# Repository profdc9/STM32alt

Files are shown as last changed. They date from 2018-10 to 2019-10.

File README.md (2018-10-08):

This is a Bluepill-compatible devboard for the STM32F103C8T6 microcontroller.
It uses all through-hole parts except for the STM32F103C8T6/STM32F103CBT6 microcontroller
and is intended to be an alternative to the Bluepill that is easier to assemble
should the Bluepill not be available or suitable.  It is somewhat optimized to be
RFI resistant given it is a two-layer board
This material is copyrighted by Daniel Marks (KW4TI) and licensed under
the Creative Commons License CC-BY-SA 4.0.  Software is copyrighted using the zlib
open-source license.

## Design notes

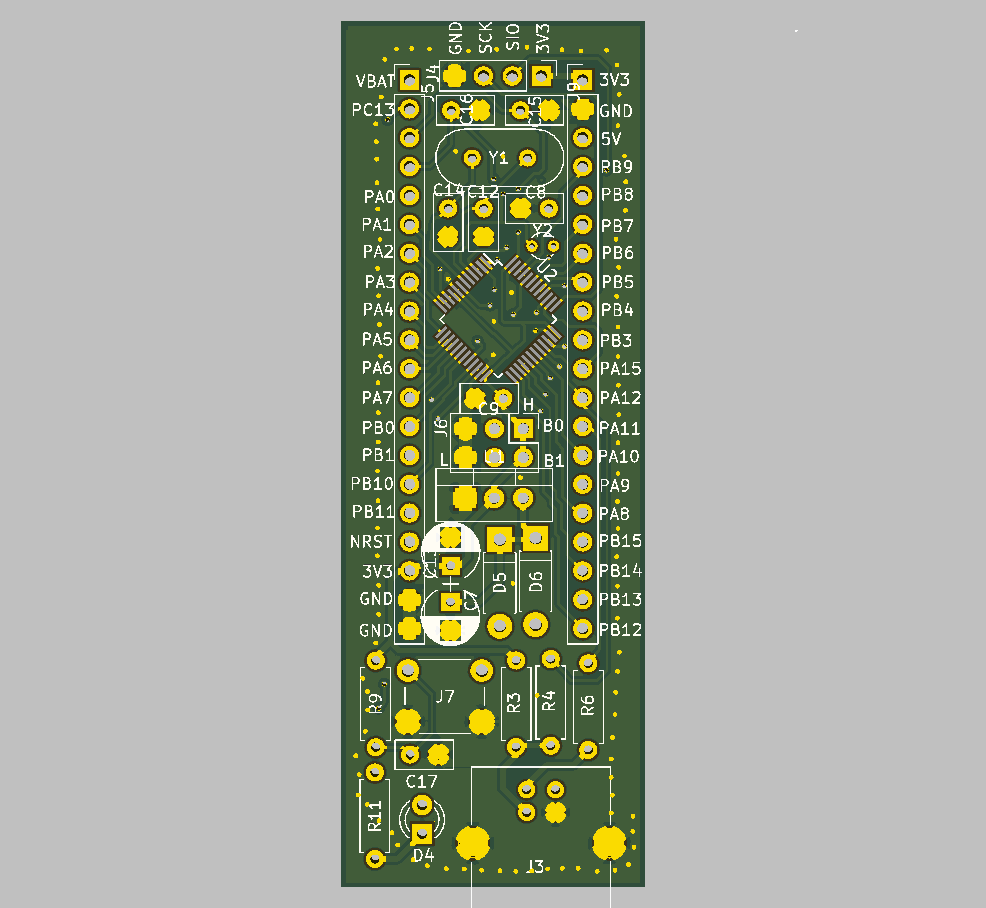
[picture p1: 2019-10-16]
STM32alt-bare.png

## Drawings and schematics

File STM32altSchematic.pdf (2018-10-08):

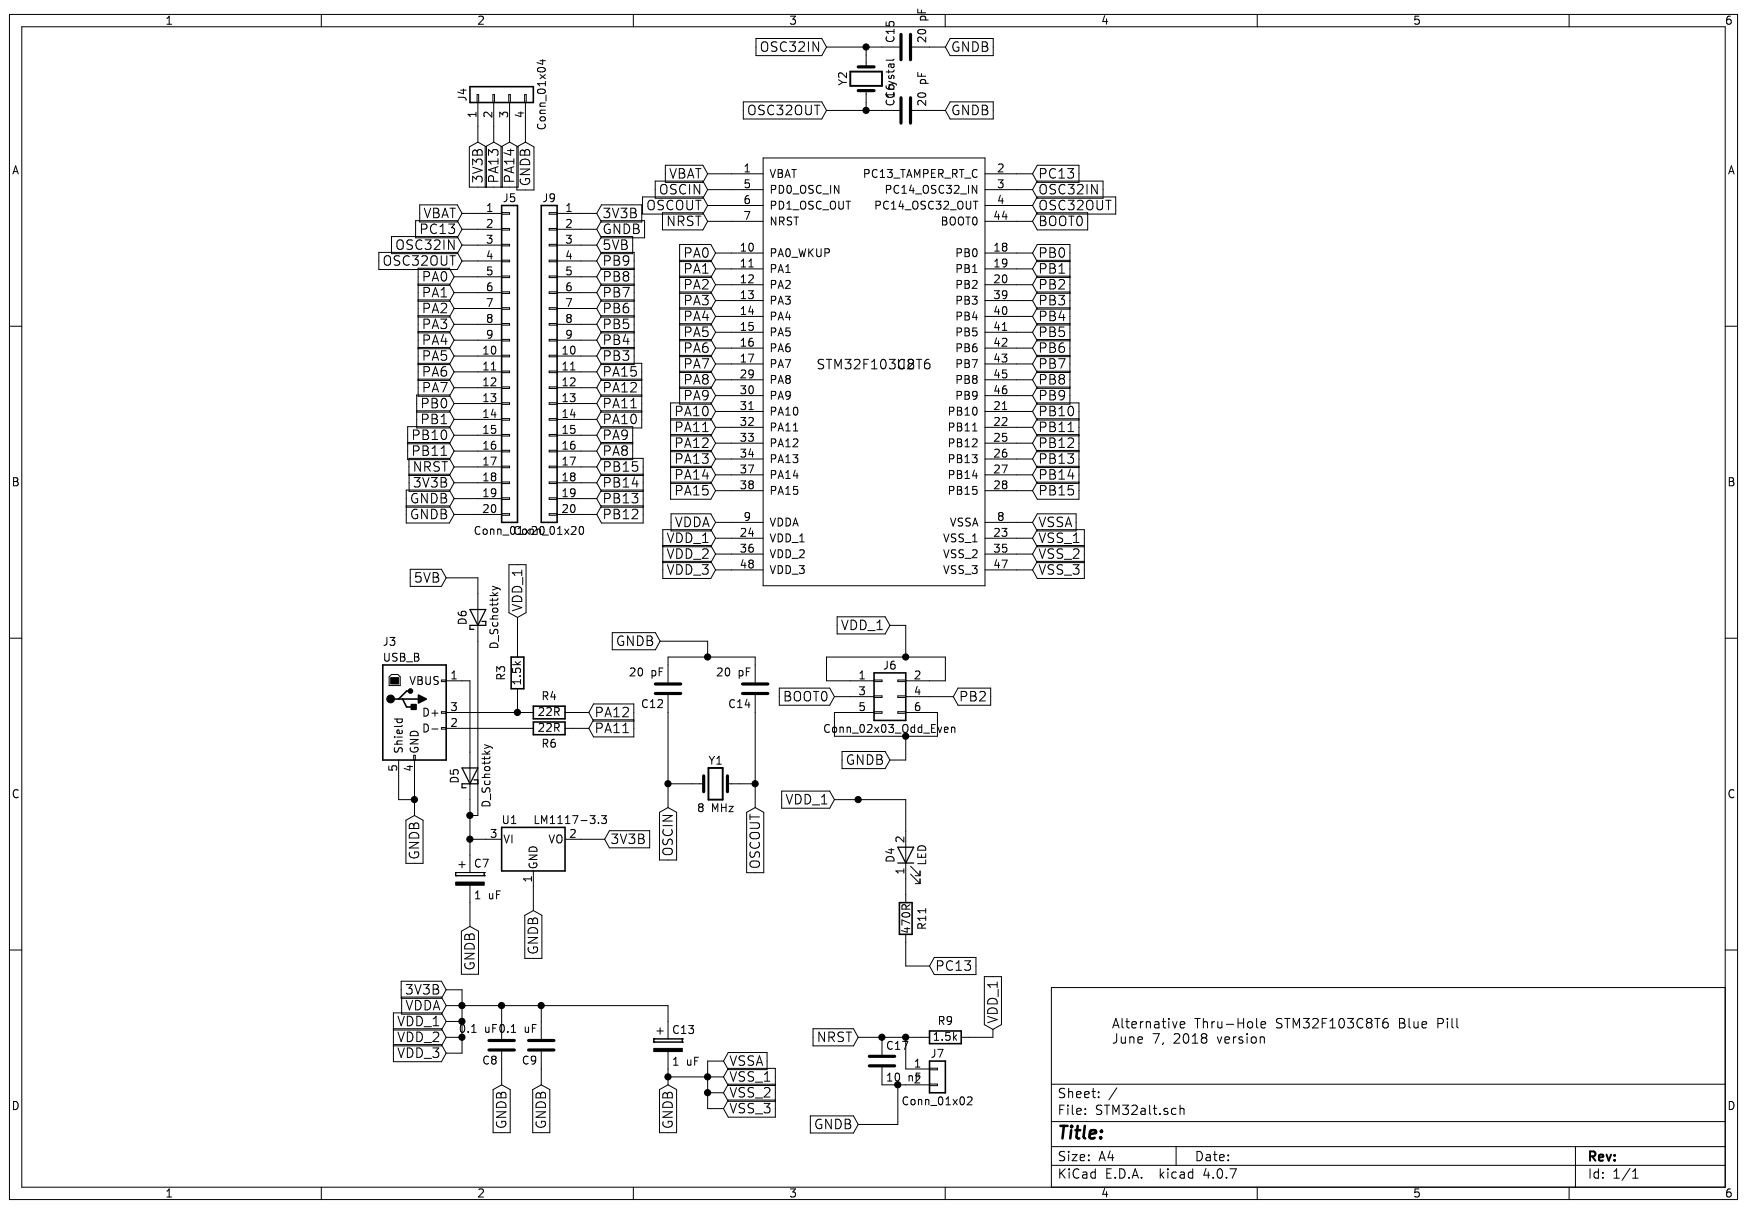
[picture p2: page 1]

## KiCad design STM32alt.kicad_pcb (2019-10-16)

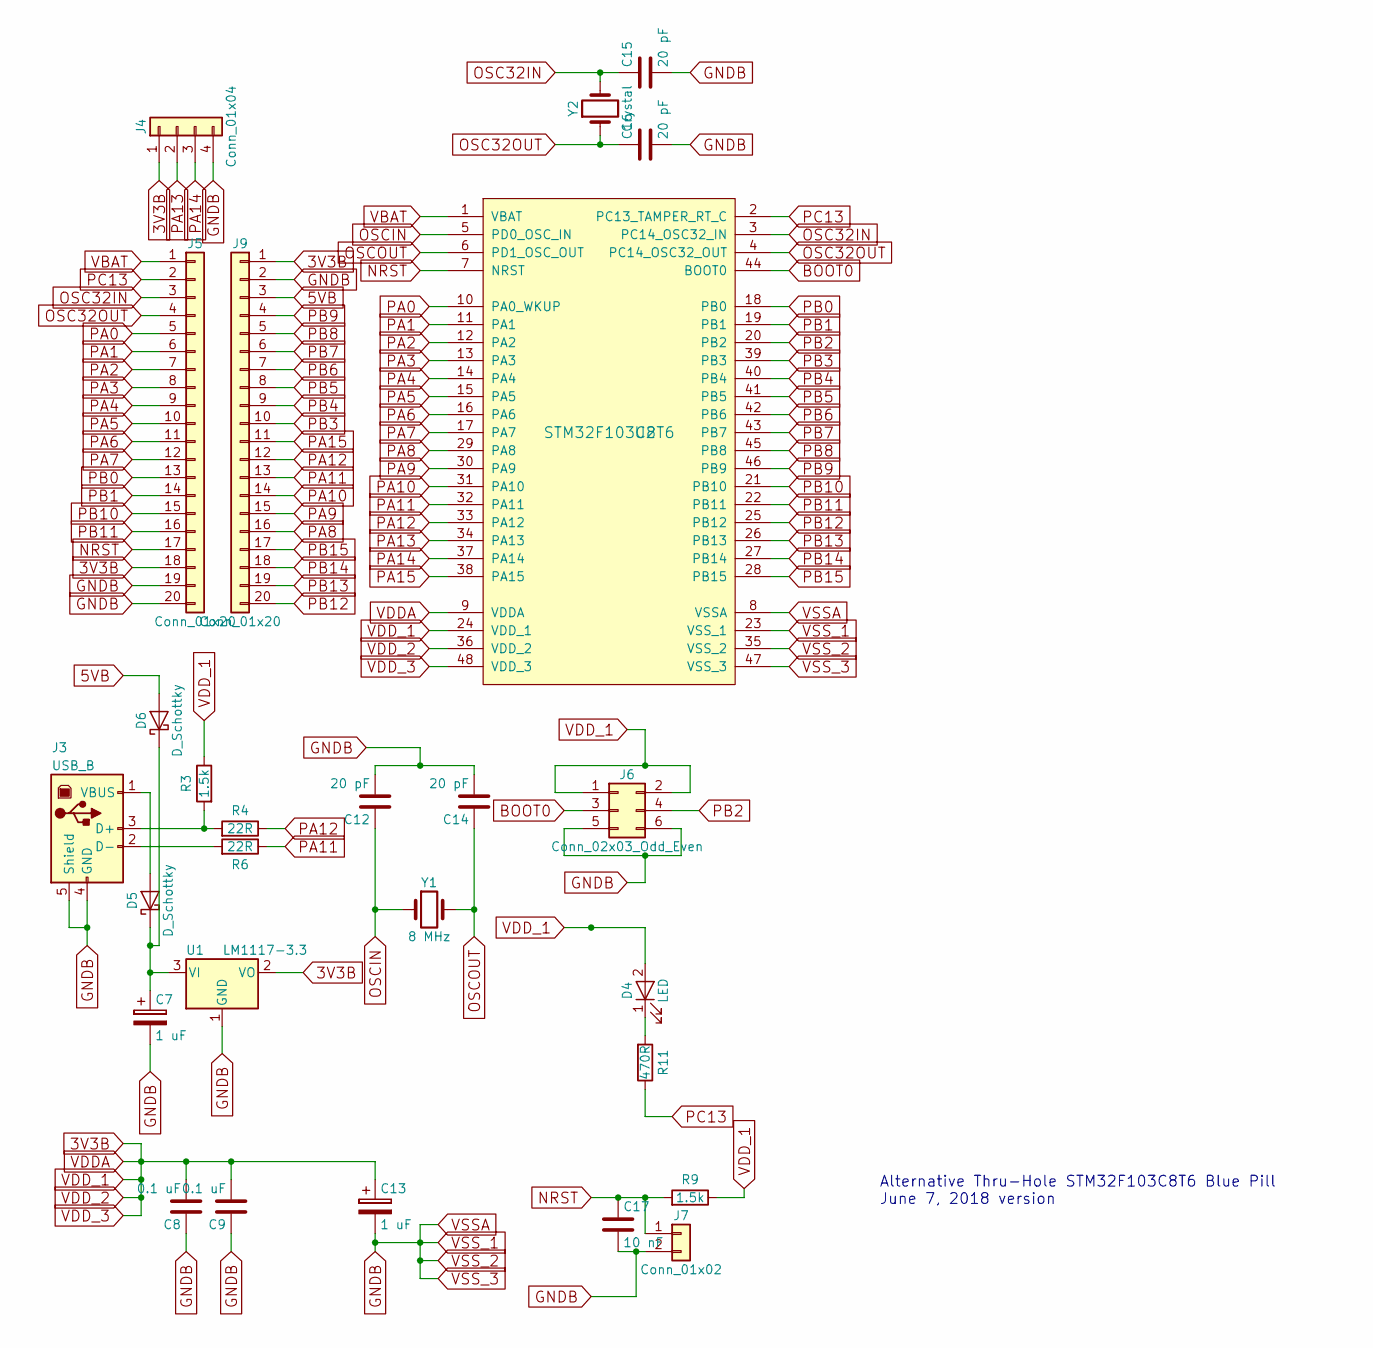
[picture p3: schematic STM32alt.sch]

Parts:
C7, C13: 1 uF; CP_Radial_D5.0mm_P2.50mm
C8, C9: 0.1 uF; C_Disc_D5.0mm_W2.5mm_P2.50mm
C12, C14, C15, C16: 20 pF; C_Disc_D5.0mm_W2.5mm_P2.50mm
C17: 10 nF; C_Disc_D5.0mm_W2.5mm_P2.50mm
D4: LED; LED_D3.0mm
D5, D6: D_Schottky; D_DO-41_SOD81_P7.62mm_Horizontal
J3: USB_B
J4: Conn_01x04; Pin_Header_Straight_1x04_Pitch2.54mm
J5, J9: Conn_01x20; Pin_Header_Straight_1x20_Pitch2.54mm
J6: Conn_02x03_Odd_Even; Pin_Header_Straight_2x03_Pitch2.54mm
J7: Conn_01x02; SW_PUSH_6mm
R3, R9: 1.5k; R_Axial_DIN0207_L6.3mm_D2.5mm_P7.62mm_Horizontal
R4, R6: 22R; R_Axial_DIN0207_L6.3mm_D2.5mm_P7.62mm_Horizontal
R11: 470R; R_Axial_DIN0207_L6.3mm_D2.5mm_P7.62mm_Horizontal
U1: LM1117-3.3; TO-220-3_Vertical
U2: STM32F103C8T6; LQFP-48_7x7mm_Pitch0.5mm
Y1: 8 MHz; Crystal_HC49-U_Vertical
Y2: Crystal; Crystal_Round_d2.0mm_Vertical

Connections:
3V3B: C8.2, C9.2, C13.1, D4.2 (A), J4.1, J5.18, J6.1, J6.2, J9.1, R3.1, R9.1, U1.2 (VO), U2.9 (VDDA), U2.24 (VDD_1), U2.36 (VDD_2), U2.48 (VDD_3)
5VB: D6.2 (A), J9.3
BOOT0: J6.3, U2.44 (BOOT0)
GNDB: C7.2, C8.1, C9.1, C12.2, C13.2, C14.2, C15.2, C16.2, C17.2, J3.4 (GND), J3.5 (Shield), J4.4, J5.19, J5.20, J6.5, J6.6, J7.2, J9.2, U1.1 (GND), U2.8 (VSSA), U2.23 (VSS_1), U2.35 (VSS_2), U2.47 (VSS_3)
NRST: C17.1, J5.17, J7.1, R9.2, U2.7 (NRST)
unnamed: C7.1, D5.1 (K), D6.1 (K), U1.3 (VI)
unnamed: D4.1 (K), R11.2
unnamed: D5.2 (A), J3.1 (VBUS)
unnamed: J3.2 (D-), R6.2
unnamed: J3.3 (D+), R3.2, R4.2
OSC32IN: C15.1, J5.3, U2.3 (PC14_OSC32_IN), Y2.2
OSC32OUT: C16.1, J5.4, U2.4 (PC14_OSC32_OUT), Y2.1
OSCIN: C12.1, U2.5 (PD0_OSC_IN), Y1.1
OSCOUT: C14.1, U2.6 (PD1_OSC_OUT), Y1.2
PA0: J5.5, U2.10 (PA0_WKUP)
PA1: J5.6, U2.11 (PA1)
PA2: J5.7, U2.12 (PA2)
PA3: J5.8, U2.13 (PA3)
PA4: J5.9, U2.14 (PA4)
PA5: J5.10, U2.15 (PA5)
PA6: J5.11, U2.16 (PA6)
PA7: J5.12, U2.17 (PA7)
PA8: J9.16, U2.29 (PA8)
PA9: J9.15, U2.30 (PA9)
PA10: J9.14, U2.31 (PA10)
PA11: J9.13, R6.1, U2.32 (PA11)
PA12: J9.12, R4.1, U2.33 (PA12)
PA13: J4.2, U2.34 (PA13)
PA14: J4.3, U2.37 (PA14)
PA15: J9.11, U2.38 (PA15)
PB0: J5.13, U2.18 (PB0)
PB1: J5.14, U2.19 (PB1)
PB2: J6.4, U2.20 (PB2)
PB3: J9.10, U2.39 (PB3)
PB4: J9.9, U2.40 (PB4)
PB5: J9.8, U2.41 (PB5)
PB6: J9.7, U2.42 (PB6)
PB7: J9.6, U2.43 (PB7)
PB8: J9.5, U2.45 (PB8)
PB9: J9.4, U2.46 (PB9)
PB10: J5.15, U2.21 (PB10)
PB11: J5.16, U2.22 (PB11)
PB12: J9.20, U2.25 (PB12)
PB13: J9.19, U2.26 (PB13)
PB14: J9.18, U2.27 (PB14)
PB15: J9.17, U2.28 (PB15)
PC13: J5.2, R11.1, U2.2 (PC13_TAMPER_RT_C)
VBAT: J5.1, U2.1 (VBAT)

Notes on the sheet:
Alternative Thru-Hole STM32F103C8T6 Blue Pill June 7, 2018 version

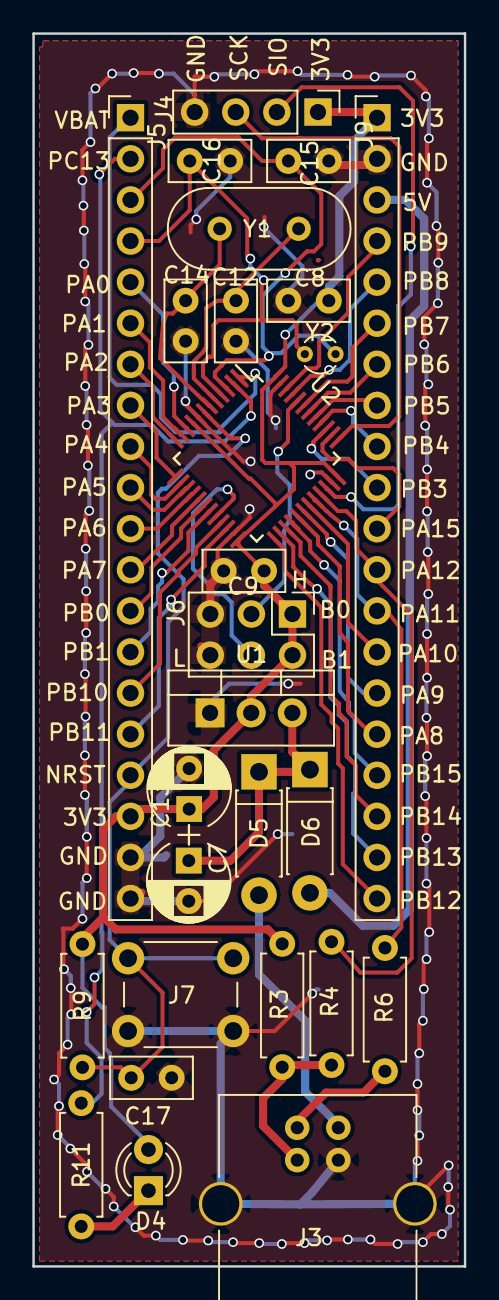
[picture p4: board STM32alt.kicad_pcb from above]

Board: 2 copper layers, 26.7 x 76.2 mm, 27 parts (0 on the bottom side), 48 nets.

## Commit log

2018-10-08 Second Commit
    [STM32alt-B.Cu.gbr, STM32alt-B.Mask.gbr, STM32alt-B.SilkS.gbr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]
2019-10-16 Moved center chip, flipped SWD connector, added ground ring
    [STM32alt-B.Cu.gbr, STM32alt-B.Mask.gbr, STM32alt-B.SilkS.gbr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]
